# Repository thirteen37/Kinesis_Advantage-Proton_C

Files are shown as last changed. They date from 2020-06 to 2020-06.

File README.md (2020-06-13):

# QMK-compatible replacement board for Kinesis Advantage

This replacement board allows you to use QMK on the [Kinesis Advantage
(KB500USB)](https://kinesis-ergo.com/support/advantage/).

This is the original version of the Kinesis Advantage and it lacks
much of the nice programmability and advanced features of the newer
[Advantage 2](https://kinesis-ergo.com/support/advantage2/) keyboards.

The replacement controller board here uses a [QMK Proton
C](https://qmk.fm/proton-c/). The replacement maintains the use of all
keys, all LEDs, and even the speaker for audio. You will also get to
replace the USB connector for a USB-C one. The only downside is that
the USB ports and optional foot pedals will not work here.

## Technical details

You can find details I reverse engineered in:

* [PCB Mechanicals](mechanical.md)
* [Wiring matrix](matrix.md)

## Assembly

### PCB Fabrication

The fabrication-ready files are in `plots/`. Just send them to your
preferred fab. It is a pretty standard 1.6mm PCB with conservative via
and track parameters that just about any shop can handle.

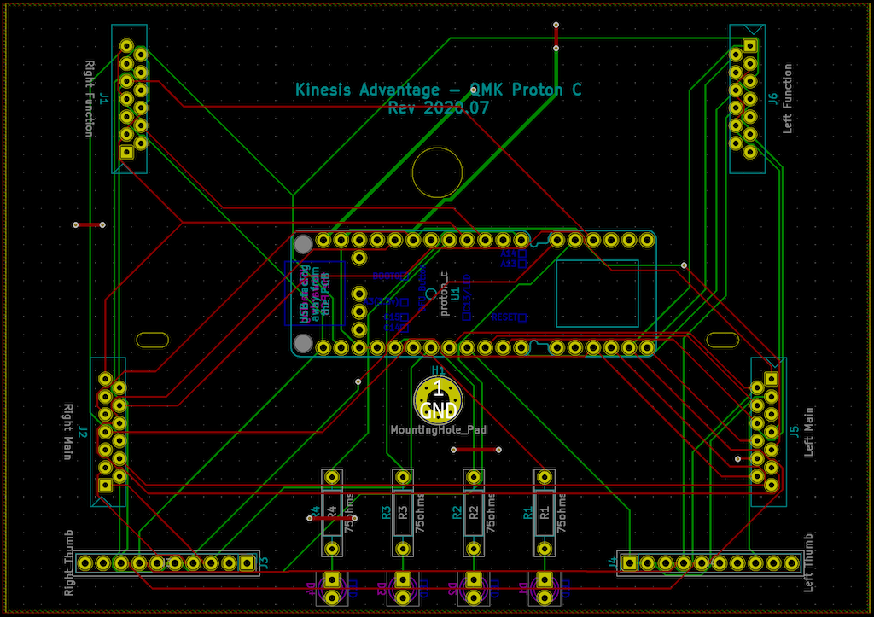
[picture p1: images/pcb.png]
PCB


### Components

* 1x [QMK Proton C](https://qmk.fm/proton-c/)
* 4x [1.25mm Pitch Easy-On FFC/FPC
    Connectors](https://www.molex.com/molex/products/part-detail/ffc_fpc_connectors/0039532135)
* 4x 3mm T-1 LEDs (see LED chart)
* 4x axial through-hole resistors, 1/4W, 1% (see LED chart)
* 2.54mm "board-to-board" pin headers
  * 2x 12 pins
  * 2x 6 pins
  * 4x 10 pins
* 2x 2.54mm 8-pin IDC-IDC ribbon cables, 100mm length minimum
* 1x USB-C cable, 1M length minimum
* (Optional) 1x AST1109MLTRQ piezo speaker

#### LEDs

I used blue LEDs in my build for a distinctive appearance. You could
use other colors or even mix and match colors. You will have to use
different resistors for each type of LED.

The LEDs are powered from Vusb @ 5V, and the Proton C's pins operate
at 3.3V and can sink a decent amount of current, allowing for a fairly
wide selection of LEDs.

The following table is a guideline for some common LED values to
operate a maximum brightness. You should check your LED datasheet to
confirm.

| LED color | LED voltage | LED current | Resistor |
|---|---|---|---|
| Blue (472nm) | 3.5V | 20mA | 75ohms |
| Red (640nm) | 1.8V | 20mA | 160ohms  |
| Yellow (590nm) | 2.0V | 20mA | 150ohms  |

### Steps

1. Disassemble keyboard
2. Replace existing ribbon cables
3. Assemble PCB
4. Re-assemble keyboard
5. Flash firmware and test

#### Disassemble keyboard

To Kinesis's credit, their keyboards are very easy to disassemble and
clean. There are six screws to remove from the bottom of the keyboard
to open it.

The USB cable is connected to a daughter board with the USB
ports. Separate the connector from the daughter board and remove the
retaining ring around the strain relief. This will allows you to
remove the USB cable completely. We will be running the new USB-C
cable through this hole. The daughter board will remain glued to the
bottom shell.

There is another cable that connects the daughter board to the main
controller board. I find it easier to remove the connector at the end
attached to the daughter board.

At this point, you can separate the bottom and top halves of the
keyboard.

You can detach the four flex cables from the main board. There is a
single retaining screw holding the main board down. Remove
this. Finally, remove the four screws on each thumb cluster. There is
a clamp on one of these screws holding the daughter board cable. Keep
this clamp as we will be reusing it later. You can now take out the
thumb cluster boards and the main board.

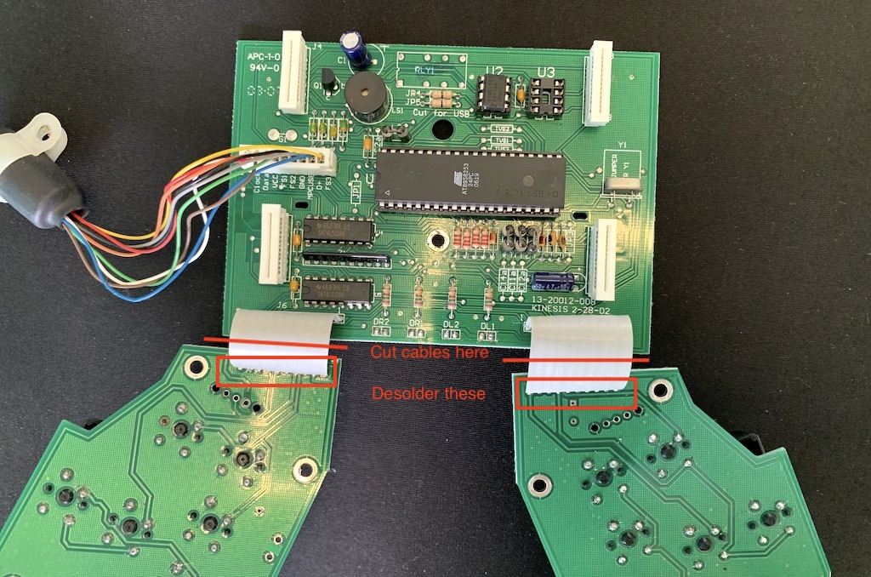
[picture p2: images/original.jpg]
Original board


#### Replace ribbon cables

Unfortunately, the cables connecting the thumb clusters to the main
board are soldered. Instead of just reconnecting this to our new
board, we will replace them with pin headers and detachable cables.

It's easiest now to just cut the cables in half and desolder them from
each of the thumb clusters. Install the pin headers. They should be
facing the side opposite the key switches. I made the mistake of
soldering them on the wrong side, necessitating another tedious
desoldering.

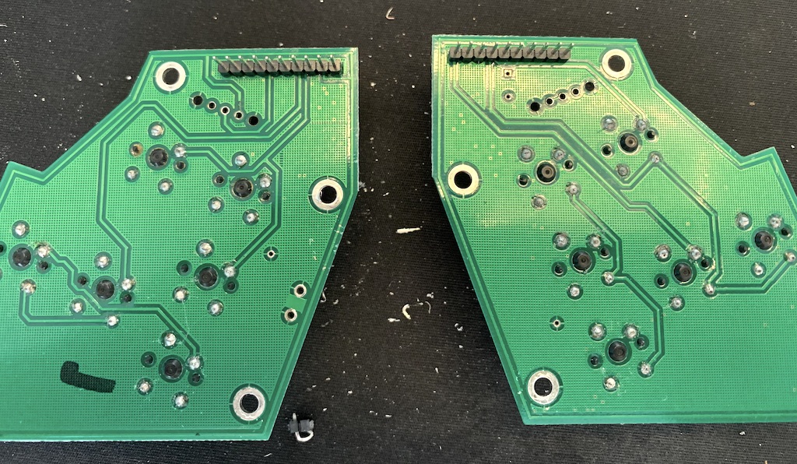
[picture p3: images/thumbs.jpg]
Thumb clusters


#### Assemble PCB

I find it easiest to assemble the board in the following order:

1. Resistors
2. FPC connectors
3. Pin headers
4. LEDs
5. Proton C

Note the orientation of the FPC connectors. There is a notch on the
short edge closest to Pin 1 and this should correspond to the small
triangle on the footprint, or the square pad.

We are only installing header pins for the external rows of the Proton
C. You can ignore the internal pins. Do also solder the pin headers
for the thumb clusters.

The LEDs are installed on the reverse side of the PCB. Take care with
their alignment as they fit loosely on the PCB but have tighter
tolerances when installed into the plastic upper shell. As always,
orientation matters for diodes and Pin 1 (square pad) is for the
negative (shorter) leg.

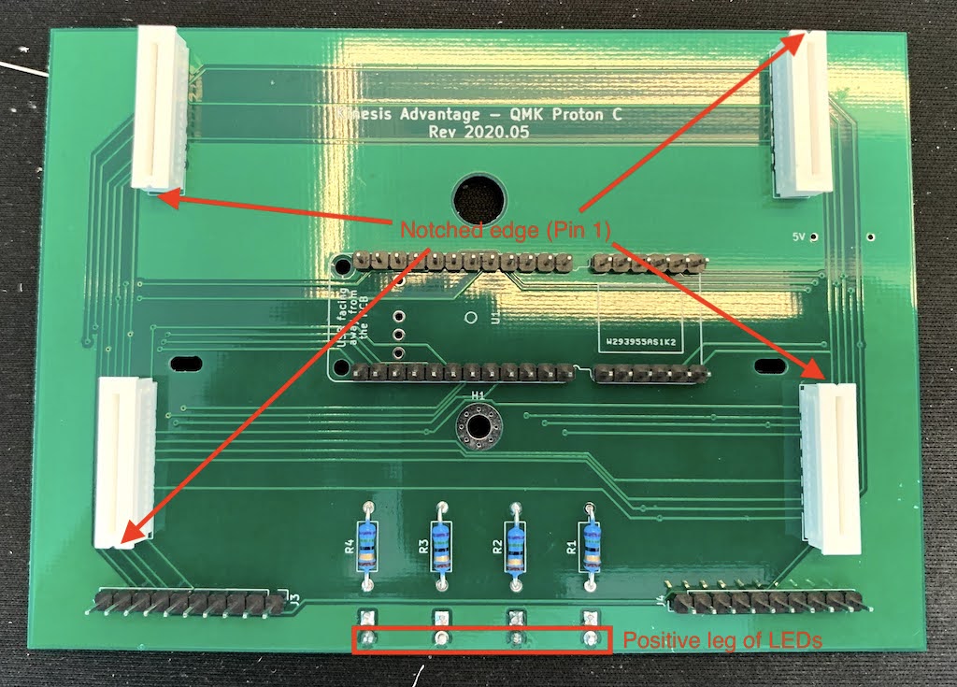
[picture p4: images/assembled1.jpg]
Passives installed


The Proton C is the last component to be soldered. It should be
installed with the USB port facing away from the PCB and towards
you. If you want to use the optional speaker, solder it to the Proton
C before installing the Proton C to the main board.

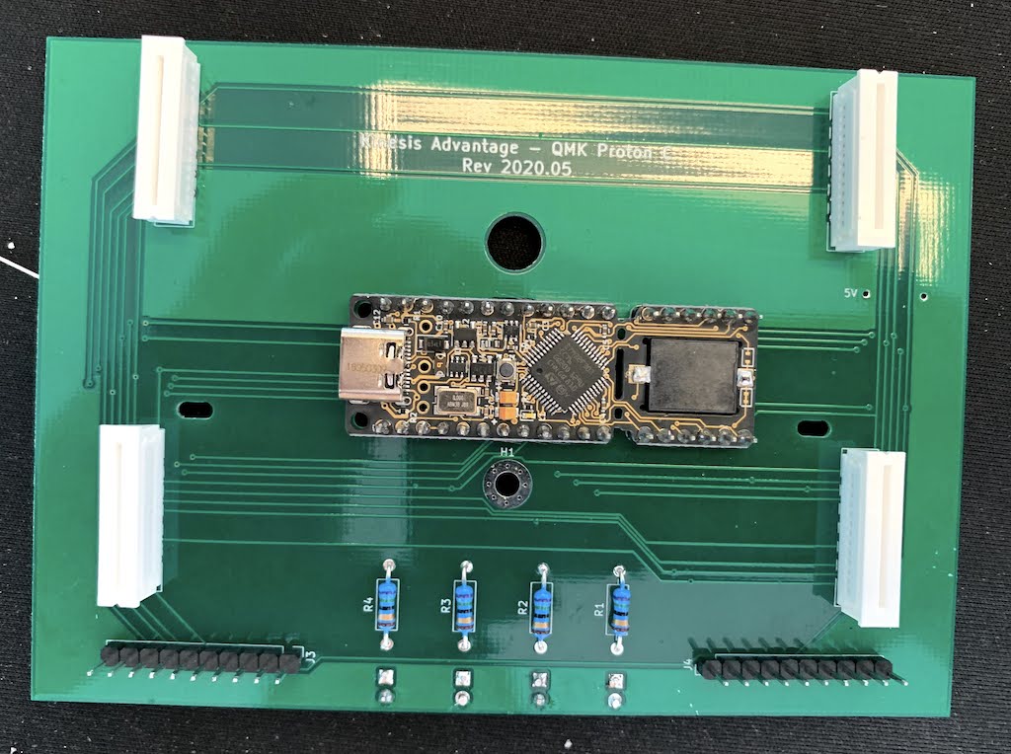
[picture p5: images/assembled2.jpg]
MCU installed


#### Re-assemble keyboard

We are only using eight of the ten pins for each thumb cluster. Make
sure you connect pins 1-8 (Pin 1 has the square pad), leaving out pins
9-10 on both the thumb cluster and main board.

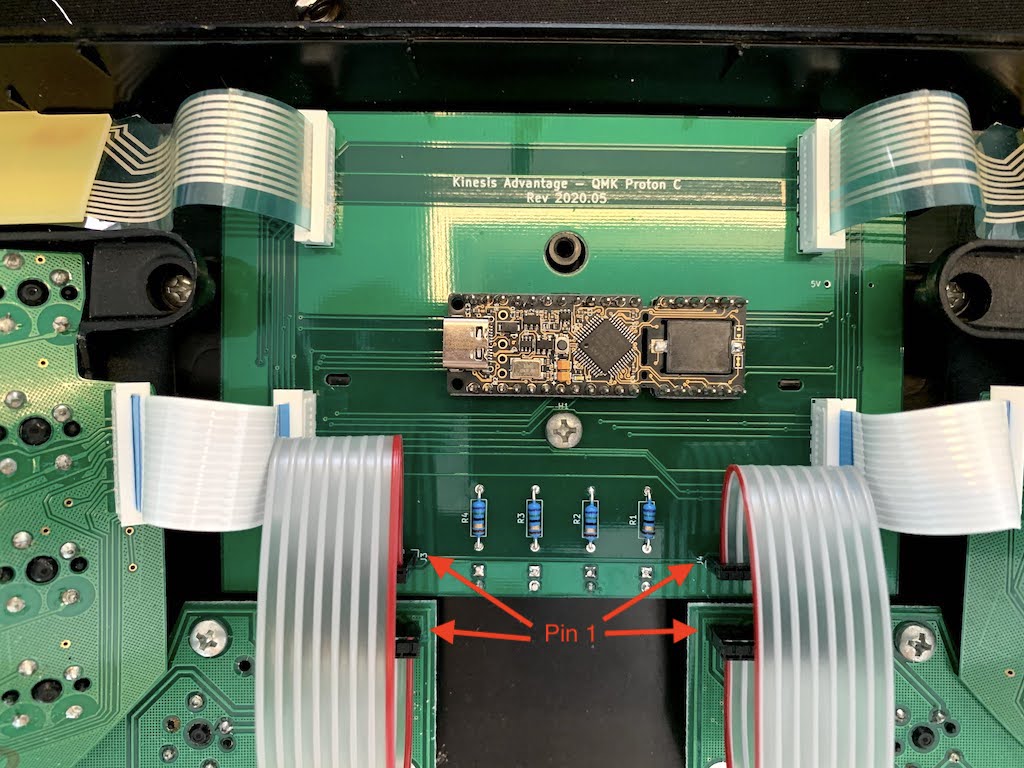
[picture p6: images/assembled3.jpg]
Board wired up


Don't forget to reinstall the clamp when attaching the screws for the
thumb clusters.

Finally, the USB C cable is plugged in to the Proton C. You will want
to loop it through the clamp to relieve strain on the Proton C
itself.

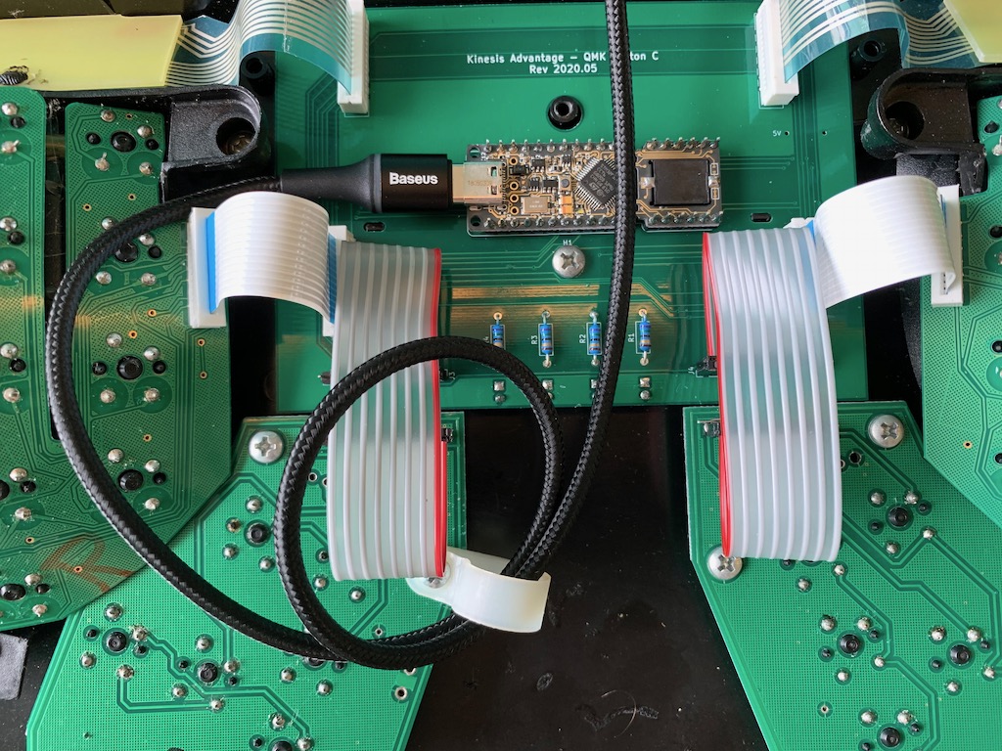
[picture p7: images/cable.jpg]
Cabling


Before closing up the bottom and top shells, flash the firmware. You
will need access to the reset button on the Proton C for the first
time you flash.

#### Flash firmware and test

The corresponding QMK firmware for this can be found at
[thirteen37/qmk_firmware](https://github.com/thirteen37/qmk_firmware/tree/kinesis_thirteen37/keyboards/kinesis/thirteen37/README.md).

A compiled version can be found in `firmware/` for you to get started
quickly. Check the [instructions on the QMK
site](https://beta.docs.qmk.fm/using-qmk/guides/flashing/flashing#stm32)
on how to flash the firmware.

# Revisions

## 2020-06

* Initial version

## 2020-07

* Don't use `SWCLK` and `SWDIO` pins unless necessary
* Move LEDs to TIM4 pins (`PB6` - `PB9`)
* Routed using Freerouting

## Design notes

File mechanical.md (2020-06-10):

# PCB Mechanicals

* PCB size: 86x122mm
* LEDs
  * 3mm T-1 green
  * 10.15 apart, center 2mm from bottom edge
* Mounting screw
  * 3.7mm diameter
  * center 30mm from bottom edge
* Mounting hole
  * 6.4mm diameter
  * center 23.7mm from top
* Connectors
  * [1.25mm Pitch Easy-On FFC/FPC
    Connector](https://www.molex.com/molex/products/part-detail/ffc_fpc_connectors/0039532135)
    for function rows and key wells.
  * Direct to board with 1.25mm pitch ribbon cables for thumb
    clusters.

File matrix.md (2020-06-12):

# Wiring matrix

## Matrix

The final matrix is implemented as such:

```
Col      0    1    2    3    4    5    6    7    8    9    10   11
Row Pins A15  B0   B1   B2   B3   B4   B5   B10  B11  B12  B13  B14
0   A0   =    1    2    3    4    5    6    7    8    9    0    -
1   A1   Tab  Q    W    E    R    T    Y    U    I    O    P    \
2   A2   CapL A    S    D    F    G    H    J    K    L    ;    '
3   A6   LSh  Z    X    C    V    B    N    M    ,    .    /    RSh
4   A7        `    \    ←         →    ↑         ↓    [    ]
5   A8   Esc  F1   F2   Home End  LALt Spc  Ent  RCtl F9   F10  F11
6   A9   F3   F4   F5   BSpc Del  LCtl PgDn GUI  PgUp F12  PSc  ScLk
7   A10  F6   F7   F8                                 Paus Kpd  Prgm
```

## LEDs

Using `PWMD4`

| Pin | PWM Channel | LED # | Function |
|-----|---|---|---|
| B6  | Ch1 | LED 1 | Caps Lock |
| B7  | Ch2 | LED 2 | Num Lock |
| B8  | Ch3 | LED 3 | Scroll Lock |
| B9  | Ch4 | LED 4 | Keypad |

## Other pins

* `A13`: `SWDIO`
* `A14`: `SWCLK`

## Individual matrices

There are a total of six separate "boards": top (function) row, main
key wells, and the thumb clusters.

The top row are silicone rubber dome switches (the newer Advantage 2
uses mechanical switches instead) and do not have diodes so may be
subject to ghosting. This is quite unlikely as you will need to
simultaneously press three or more of those switches to get a ghost.

The other switches are all mechanical Cherry Browns. Each has a
through-hole diode hidden in them with the pins coming out of the
bottom of the switch as would if you had installed an LED for the
switch. The diode's polarity is "row-to-column".

For the main key wells, the matrix layout is largely orthogonal, with
clear rows and columns. In our matrix, we connect both sides of each
row to form a single contiguous row.

The thumb clusters and function rows have weird matrices that use far
more pins than necessary. Fortunately, we are able to pack this down
to three rows and the same 12 columns used by the main key wells.

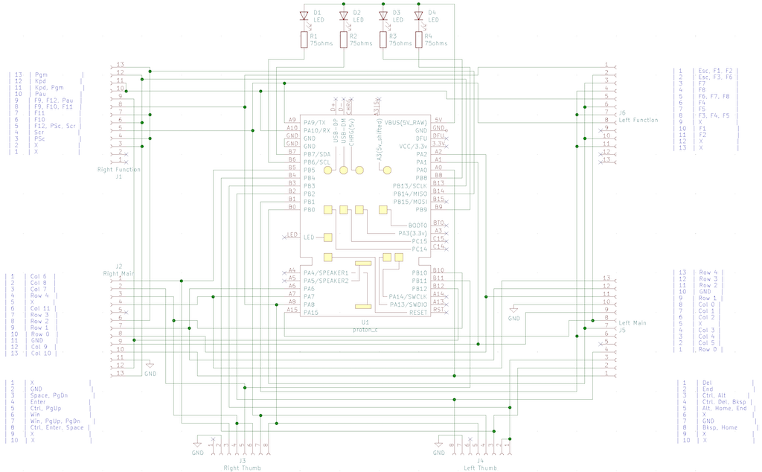
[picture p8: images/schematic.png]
Schematic


What follows are the pinouts for each matrix.

### Top left

| Pin | Keys |
|-----|---|
| 1 | Esc, F1, F2 |
| 2 | Esc, F3, F6 |
| 3 | F7 |
| 4 | F8 |
| 5 | F6, F7, F8  |
| 6 | F4 |
| 7 | F5 |
| 8 | F3, F4, F5  |
| 9 | X |
| 10  | F1 |
| 11  | F2 |
| 12  | X |
| 13  | X |

### Top right

| Pin | Keys |
|-----|---|
| 13  | Pgm |
| 12  | Kpd |
| 11  | Kpd, Pgm |
| 10  | Pau |
| 9 | F9, F12, Pau  |
| 8 | F9, F10, F11  |
| 7 | F11 |
| 6 | F10 |
| 5 | F12, PSc, Scr |
| 4 | Scr |
| 3 | PSc |
| 2 | X |
| 1 | X |

### Middle left

Columns are left to right, rows are top to bottom.

| Pin | Keys  |
|-----|---|
| 13  | Row 4 |
| 12  | Row 3 |
| 11  | Row 2 |
| 10  | GND |
| 9 | Row 1 |
| 8 | Col 0 |
| 7 | Col 1 |
| 6 | Col 2 |
| 5 | X |
| 4 | Col 3 |
| 3 | Col 4 |
| 2 | Col 5 |
| 1 | Row 0 |

### Middle right

Columns are left to right, rows are top to bottom.

| Pin | Keys |
|-----|---|
| 1 | Col 6  |
| 2 | Col 8  |
| 3 | Col 7  |
| 4 | Row 4  |
| 5 | X |
| 6 | Col 11 |
| 7 | Row 3  |
| 8 | Row 2  |
| 9 | Row 1  |
| 10  | Row 0  |
| 11  | GND |
| 12  | Col 9  |
| 13  | Col 10 |

### Bottom left

| Pin | Keys |
|-----|---|
| 1 | Del |
| 2 | End |
| 3 | Ctrl, Alt |
| 4 | Ctrl, Del, Bksp |
| 5 | Alt, Home, End  |
| 6 | X |
| 7 | GND |
| 8 | Bksp, Home |
| 9 | X |
| 10  | X |

### Bottom right

| Pin | Keys |
|-----|---|
| 1 | X |
| 2 | GND |
| 3 | Space, PgDn |
| 4 | Enter |
| 5 | Ctrl, PgUp |
| 6 | Win |
| 7 | Win, PgUp, PgDn |
| 8 | Ctrl, Enter, Space |
| 9 | X |
| 10  | X |

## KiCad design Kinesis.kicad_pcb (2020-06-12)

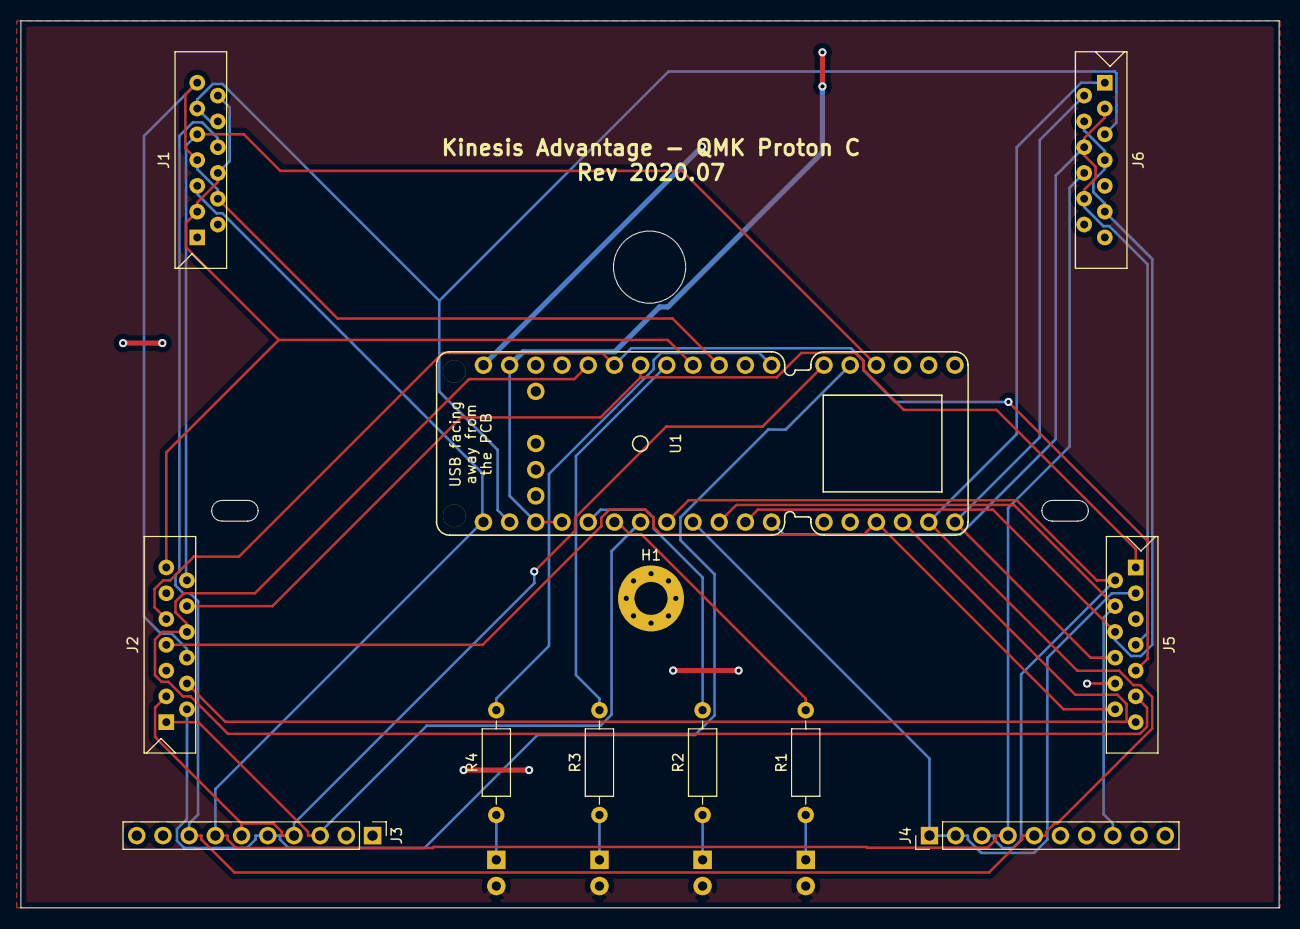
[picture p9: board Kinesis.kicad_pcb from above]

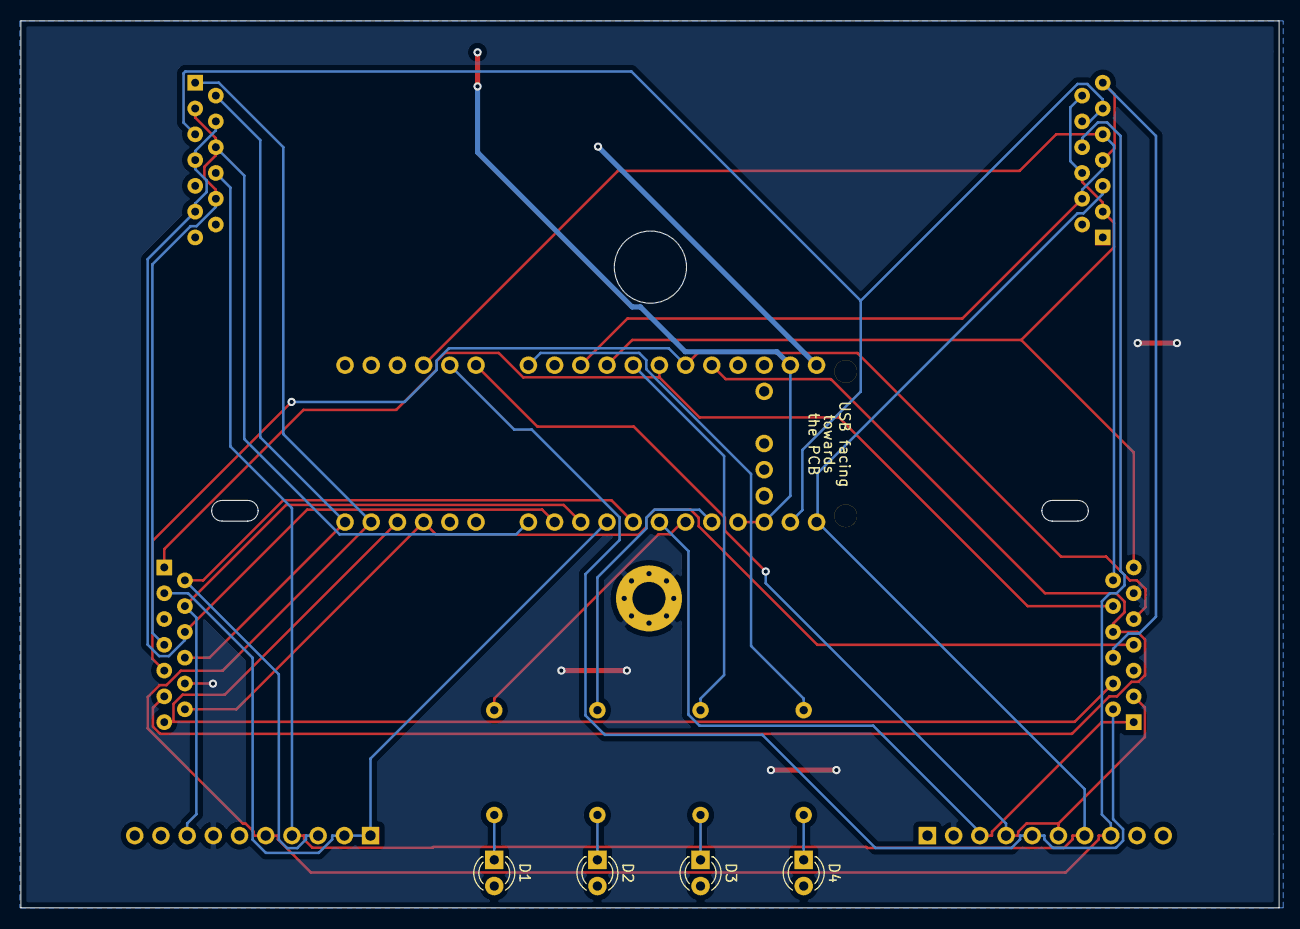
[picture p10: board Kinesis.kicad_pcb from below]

Board: 2 copper layers, 122.0 x 86.0 mm, 16 parts (4 on the bottom side), 30 nets.

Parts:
D1, D2, D3, D4: LED; LED_D3.0mm
H1: MountingHole_Pad; MountingHole_3.2mm_M3_Pad_Via
J1: Right Function; Molex_FFC-FPC_Easy-On_39-53-2135_13-Contact_Vertical
J2: Right Main; Molex_FFC-FPC_Easy-On_39-53-2135_13-Contact_Vertical
J3: Right Thumb; PinHeader_1x10_P2.54mm_Vertical
J4: Left Thumb; PinHeader_1x10_P2.54mm_Vertical
J5: Left Main; Molex_FFC-FPC_Easy-On_39-53-2135_13-Contact_Vertical
J6: Left Function; Molex_FFC-FPC_Easy-On_39-53-2135_13-Contact_Vertical
R1, R2, R3, R4: 75ohms; R_Axial_DIN0207_L6.3mm_D2.5mm_P10.16mm_Horizontal
U1: proton_c

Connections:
GND: H1.1, J2.11, J3.2, J4.7, J5.10
unnamed: D1.1, R1.1
unnamed: D1.2, D2.2, D3.2, D4.2, U1.5V
unnamed: D2.1, R2.1
unnamed: D3.1, R3.1
unnamed: D4.1, R4.1
unnamed: J1.5, J3.7, J4.4, J6.8, U1.A9
unnamed: J1.8, J3.8, J4.5, J6.1, U1.A8
unnamed: J1.9, J2.12, U1.B12
unnamed: J1.10, J1.11, J6.5, U1.A10
unnamed: J1.3, J1.6, J1.12, J2.13, U1.B13
unnamed: J1.4, J1.7, J1.13, J2.6, U1.B14
unnamed: J2.1, J3.3, U1.B5
unnamed: J2.2, J3.5, U1.B11
unnamed: J2.3, J3.4, J3.6, U1.B10
unnamed: J2.4, J5.13, U1.A7
unnamed: J2.7, J5.12, U1.A6
unnamed: J2.8, J5.11, U1.A2
unnamed: J2.9, J5.9, U1.A1
unnamed: J2.10, J5.1, U1.A0
unnamed: J4.1, J4.2, J5.3, U1.B3
unnamed: J4.3, J5.2, U1.B4
unnamed: J4.8, J5.4, U1.B2
unnamed: J5.6, J6.4, J6.7, J6.11, U1.B1
unnamed: J5.7, J6.3, J6.6, J6.10, U1.B0
unnamed: J5.8, J6.2, U1.A15
unnamed: R1.2, U1.B6
unnamed: R2.2, U1.B7
unnamed: R3.2, U1.B8
unnamed: R4.2, U1.B9

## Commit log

2020-06-10 Squashed 'libs/qmk_hardware/' content from commit 64f0be6
    git-subtree-dir: libs/qmk_hardware
    git-subtree-split: 64f0be61e7f44833726313cccbe1bc0ecc0afbe8
    [BG030-06-A-0400-0300-N-G.stp, BG030-12-A-0400-0300-N-G.stp, kailh-socket-choc.stp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]
2020-06-10 Fix module libraries
    [Kinesis.kicad_pcb]
2020-06-10 PCB components
2020-06-10 Add resistor chart
2020-06-10 Next part of assembly instructions
2020-06-11 PCB fab instructions and images
    [Kinesis-B_Cu.gbr, Kinesis-B_Mask.gbr, Kinesis-B_Paste.gbr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]
2020-06-11 Fix Molex footprints
    [Kinesis.kicad_pcb, Kinesis.sch]
2020-06-12 Use TIM4 for LEDs
    Also free up debug pins
    [Kinesis-B_Cu.gbr, Kinesis-B_Mask.gbr, Kinesis-B_Paste.gbr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]
